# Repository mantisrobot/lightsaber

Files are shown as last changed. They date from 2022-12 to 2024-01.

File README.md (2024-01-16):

# minifig_lightsaber
Giant Scale Minifig Lightsaber Source

This source includes two libraries that have not been written byt me. The FlashStorage library and the samd21 audio library. However, I have made changes to tbe audio library to include a loop sample function.

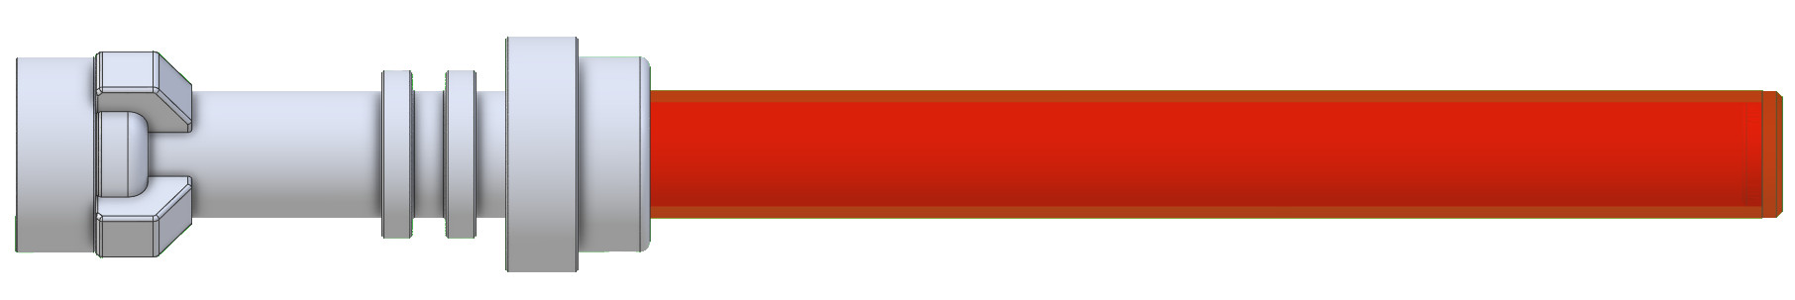
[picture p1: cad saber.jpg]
Lightsaber Minifig Lightsaber


Check out the origonal build video here:
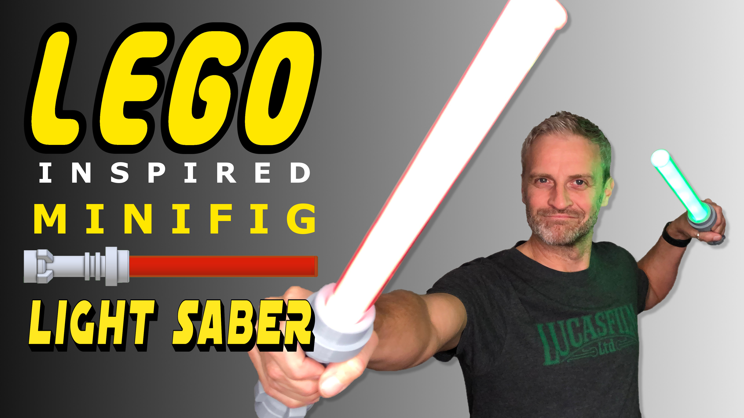
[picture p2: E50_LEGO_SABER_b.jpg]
Watch the video (https://youtu.be/OPCm9aoIxUs)


Suport my channel by purchaseing the STL files here:
https://www.threeding.com/3d-model/14297-giant-scale-minifig-light-saber

Minifig Light Saber Schematic:
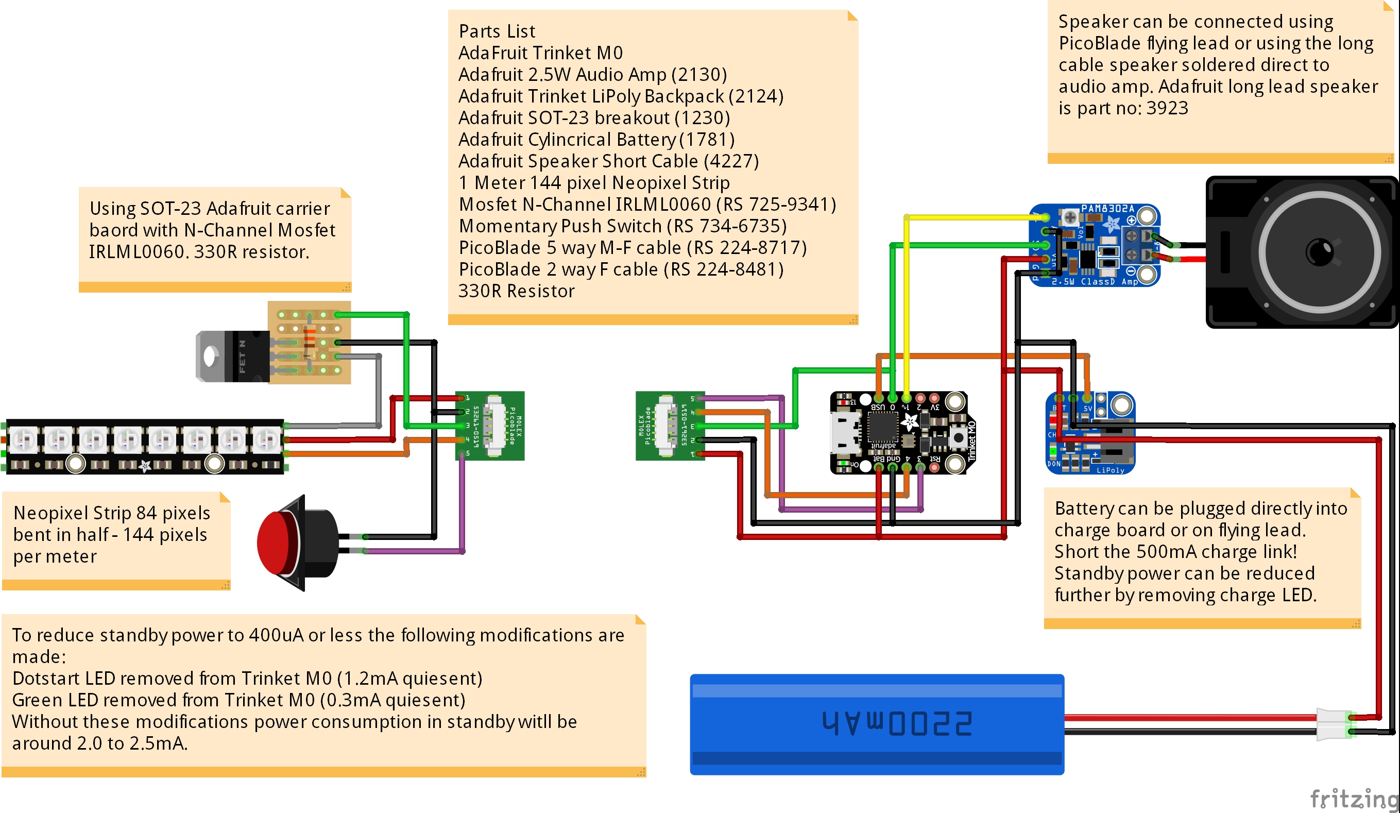
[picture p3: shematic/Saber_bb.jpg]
schematic Schematic


## Arduino Project
The arduino audio library has been modified to add a loopAudio() function. I have included my version of the library in the LIBS directory. You will need to copy the audio libray directory to your arduino libray directory.

## Parts List
Reference links provided in the [Parts List](./Denton%20Saber%20Parts.xls)

*********************************
Amazon Parts US Links:
*********************************
- Adafruit Trinket M0: https://amzn.to/3VEV7Ne
- Adafruit LiPo Backpack: https://amzn.to/3VIdf8Z
- 2.5W Class D Amplifier: https://amzn.to/3FdEK4N
- 1W Oval Speaker: https://amzn.to/3AXXmTQ
- Neopixel Strip: https://amzn.to/3XMaK7a
- SOT-23 Breakout PCB: https://amzn.to/3Ulr6AG
- Polymaker PLA Grey 1.75mm: https://amzn.to/3UnYiYk
- Polymaker PLA Grey 2.85mm: https://amzn.to/3H29UgL

*********************************
Amazon Parts UK Links:
*********************************
- Adafruit Trinket M0: https://amzn.to/3VFpXFe
- Adafruit LiPo Backpack: https://amzn.to/3VhMpEB
- 2.5W Class D Amplifier: https://amzn.to/3ESpicO
- 1W Oval Speaker: https://amzn.to/3uamDGr
- Neopixel Strip: https://amzn.to/3VzjxaM
- SOT-23 Breakout PCB: https://amzn.to/3Fexrd9
- SOT-23 Breakout PCB: https://amzn.to/3GSifDI
- 3.7V 18650 LiPo Battery: https://shop.pimoroni.com/products/lithium-ion-battery-pack?variant=23417820359
- Polymaker PLA Grey 1.75mm: https://amzn.to/3EUrOPH
- Polymaker PLA Grey 2.85mm: https://amzn.to/3H1n912
- Acrylic Tube 32x28x500mm (requires cutting down): https://amzn.to/3Uq9hAF

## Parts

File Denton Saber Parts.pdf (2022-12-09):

### Sheet1

### Page 1

# Denton Minifig Light Saber Part List

Description | Qty Link | Alternate Link List Price (US) | Notes
Adafruit Trinket M0 | 1 https://www.adafruit.com/product/3500 https://www.digikey.com/en/products/detail/adafruit-industries-llc/3500/7623049 $ | 8.95
Adafruit LiPo Backpack | 1 https://www.adafruit.com/product/2124 https://www.digikey.com/en/products/detail/adafruit-industries-llc/2124/5761211 $ | 4.95
Adafruit Speaker | 1 https://www.adafruit.com/product/4227 https://www.digikey.com/en/products/detail/adafruit-industries-llc/4227/10245140 $ | 1.95
Adafruit Amplifier | 1 https://www.adafruit.com/product/2130 https://www.digikey.com/en/products/detail/adafruit-industries-llc/2130/5761279 $ | 3.95
Adafruit SOT-23 Carrier | 1 https://www.adafruit.com/product/1230 https://www.digikey.com/en/products/detail/adafruit-industries-llc/1230/5022801 $ | 4.95
Adafruit LiPo Battery | 1 https://www.adafruit.com/product/1781 https://www.digikey.com/en/products/detail/adafruit-industries-llc/1781/5054543 $ | 9.95 | Cable may need lengthening, check polarity!
Neopixel Strip (144 pixels/meter) UK | 1 https://amzn.to/3irY999 | Either UK Link
Neopixel Strip (144 pixels/meter) US | https://amzn.to/3UjBZTU | Or US Link
Switch | 1 https://uk.rs-online.com/web/p/push-button-switches/7346735 https://www.digikey.com/en/products/detail/cit-relay-and-switch/BNP10SCQE/12503300 $ | 2.39
Picoblade Cable (5-pin) | 1 https://uk.rs-online.com/web/p/wire-to-board-cables/2248717 https://www.digikey.com/en/products/detail/molex/2181130502/14309366 $ | 4.70
Picoblade Cable (2-in) | 1 | https://www.digikey.com/en/products/detail/molex/2181110200/14309356 $ | 2.11
FET Transitor | 1 https://uk.rs-online.com/web/p/mosfets/7259341 https://www.digikey.com/en/products/detail/infineon-technologies/IRLML0060TRPBF/2202213 $ | 0.51
330R Resistor | 1 | https://www.digikey.com/en/products/detail/yageo/FMP100JR-52-330R/2058601 $ | 0.20
M2.5 Square Nut | 2 | https://www.digikey.com/en/products/detail/wakefield-vette/3654370/5432347
M2.5 x 12 Cap Head Bolt | 2 | https://www.digikey.com/en/products/detail/essentra-components/50M025045G012/11640243 $ | 0.15
Acrylic Tube | 1 https://www.ebay.co.uk/itm/200973097176?var=500191833720 | 32mm OD, 28mm ID, 300mm Length

Amazon Parts Links

### Sheet1

### Page 2

Amazon US | Amazon UK
https://amzn.to/3VEV7Ne | https://amzn.to/3VFpXFe
https://amzn.to/3VIdf8Z | https://amzn.to/3VhMpEB
https://amzn.to/3AXXmTQ | https://amzn.to/3uamDGr
https://amzn.to/3FdEK4N | https://amzn.to/3ESpicO

Cable may need lengthening, check polarity!
https://amzn.to/3XMaK7a | https://amzn.to/3VzjxaM
32mm OD, 28mm ID, 300mm Length | https://www.amazon.com/gp/product/B0B6QBDQGN/

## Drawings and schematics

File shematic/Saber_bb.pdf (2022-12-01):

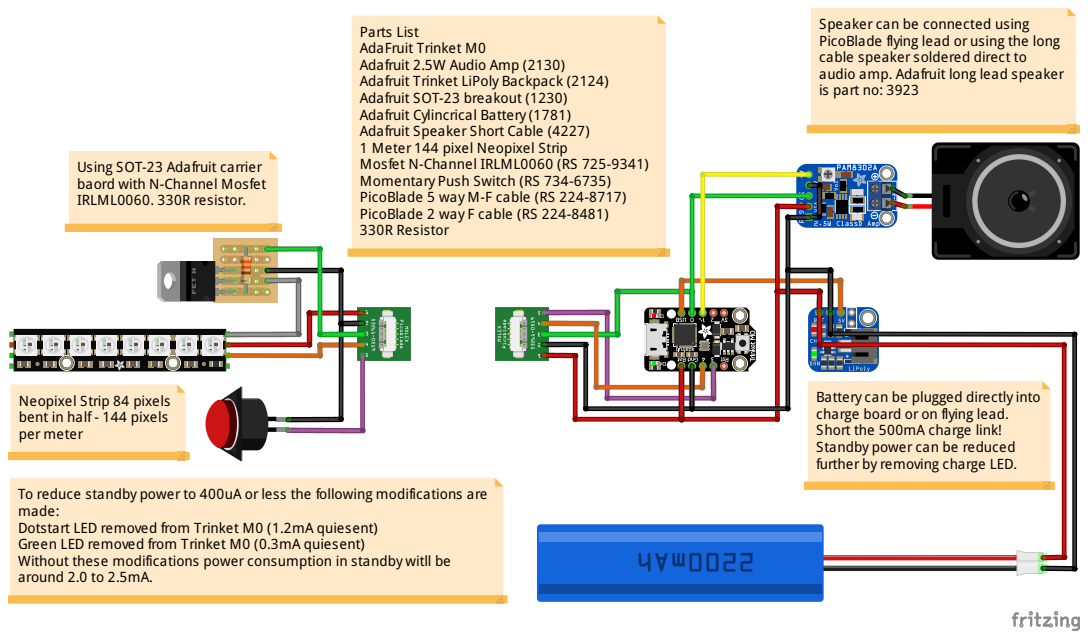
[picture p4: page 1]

Speaker can be connected using
PicoBlade flying lead or using the long
cable speaker soldered direct to
audio amp. Adafruit long lead speaker
is part no: 3923

Parts List
AdaFruit Trinket M0
Adafruit 2.5W Audio Amp (2130)
Adafruit Trinket LiPoly Backpack (2124)
Adafruit SOT-23 breakout (1230)
Adafruit Cylincrical Battery (1781)
Adafruit Speaker Short Cable (4227)
1 Meter 144 pixel Neopixel Strip
Mosfet N-Channel IRLML0060 (RS 725-9341)
Momentary Push Switch (RS 734-6735)
PicoBlade 5 way M-F cable (RS 224-8717)
PicoBlade 2 way F cable (RS 224-8481)
330R Resistor

Using SOT-23 Adafruit carrier
baord with N-Channel Mosfet
IRLML0060. 330R resistor.

Neopixel Strip 84 pixels
bent in half - 144 pixels
per meter

Battery can be plugged directly into
charge board or on flying lead.
Short the 500mA charge link!
Standby power can be reduced
further by removing charge LED.

To reduce standby powerto 400uA orless the following modifications are
made:
Dotstart LED removed from Trinket M0 (1.2mA quiesent)
Green LED removed from Trinket M0 (0.3mA quiesent)
Without these modifications power consumption in standby witll be
around 2.0 to 2.5mA.

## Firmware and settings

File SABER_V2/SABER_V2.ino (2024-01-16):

//#include <Adafruit_NeoPixel_ZeroDMA.h>
#include <Adafruit_NeoPixel.h>
#include <AudioPlayer.h>
#include <Adafruit_DotStar.h>
#include "ArduinoLowPower.h"
#include <FlashStorage.h>
#include "ON_1S.h"
#include "OFF_06S.h"
#include "HUM_3SM.h"

// NEOPIXEL DMA
// using DMA mode frees up processor use and does not distort sound, however, there is no
// mechanisim to disable the library and set the neopixel pin back to an input, which means there
// is a higher current draw in sleep mode. For this reason I have switched to the standard neopixel
// lib and uses setPin() to disable the neopixel output reducing the sleep current. Also, the 
// sound distortion produced is acceptable and actually quite good!


// this option does not playback sound, just used during development
//#define MUTE_MODE

// do not sleep when debuging / developing
// Once the device enters sleep mode, you will not be able to program the device from the arduino IDE without
// power cycling the device. This mode stops the device from going into a full sleep while developing code.
//#define DEBUG_NO_SLEEP_MODE

#define USE_INTERRUPT_PIN
// this option uses pin change wake up, much faster power on than timed sleep mode!

// defines the strip update rate
#define FRAME_RATE 50

// defines the nuber of neopixels on one side of the strip. (actual count is twice this number)
#define STRIP_LED_COUNT 42

// boot delay useful when developing
// This boot delay gives time for the device to be programmed after applying power.
// Once the device goes to sleep programming can not take effect unless a power cycle is inititated.
// See DEBUG_NO_SLEEP_MODE option above for further development mode option.
#define BOOT_TIME_WAIT  30000 // mili seconds


// ************************************************************************
// device pins
// ************************************************************************
#define PIN_ANA_OUT     A0
#define PIN_NEOPIXEL    4
#define PIN_SPARE       2
#define PIN_AMP_SHDWM   0
#define PIN_WAKE        3
#define PIN_DUMMY       9

// ************************************************************************
// AUDIO SECTION
// ************************************************************************
/*
 * WAV CONVERSION TO .h FILES
 * https://bitluni.net/wp-content/uploads/2016/12/bin2h8bit.html
 */

#define WAV_FREQUENCEY  16000
#define WAV_OVERSAMPLE  0
#define SABER_ON_TIME (saberOnSize / (WAV_FREQUENCEY/1000)) // power up time in mS
#define SABER_OFF_TIME (saberOffSize / (WAV_FREQUENCEY/1000)) // power down time in mS

// ************************************************************************
// these values set the color and intesity. I have tuned these to keep below 
// 650ma of power draw! This is due to the small wires used on the picoblade
// connector which have a mximum of 1000ma capacity.
// ************************************************************************
#define BLADE_COLOR_RED (0xA00000)
#define BLADE_COLOR_YEL (0x784200)
#define BLADE_COLOR_GRN (0x007200)
#define BLADE_COLOR_BLU (0x0000B0)
#define BLADE_COLOR_PUR (0x600060)
#define BLADE_COLOR_WHT (0x402855)

#define MAX_COLORS 6
const unsigned long saberColor[MAX_COLORS] = {BLADE_COLOR_RED,BLADE_COLOR_YEL,BLADE_COLOR_GRN,BLADE_COLOR_BLU,BLADE_COLOR_PUR,BLADE_COLOR_WHT};

// used by fast sin table
#define SIN_TABLE_SCALE 10  // fractions of a degree, e.g. 10 = 0.1 degrees per step tabel size = 360 * 10

// saber pixel array
unsigned long saberPixels[STRIP_LED_COUNT];

// saber pulse variables
#define WAVE_AMPLITUDE_RND (waveAmplitude) //(saberColorRndAmplitude[saberColIndex])
#define WAVE_FREQUENCY_MIN (20)
#define WAVE_FREQUENCY_RND (waveFrequency)
#define WAVE_PHASE_MIN     (-10)
#define WAVE_PHASE_RND     (wavePhase)


// ************************************************************************
// neopixel and dotstart strip 
// ************************************************************************
Adafruit_NeoPixel strip(STRIP_LED_COUNT * 2, PIN_NEOPIXEL, NEO_GRB);
Adafruit_DotStar dotStar = Adafruit_DotStar(1, 7, 8, DOTSTAR_BGR);

// ************************************************************************
// variables and functions
// ************************************************************************
volatile bool  wake = false;
int   saberColIndex = 0;
int   waveFrequency = 25;
int   wavePhase = 10;
float waveAmplitude = 0.5;
float degrees = 0;
float sinTable[360*SIN_TABLE_SCALE];


void wakeUp(void);
void sleepSaber(void);
void powerUpSaber(void);
void powerDownSaber(void);
void powerDownDevice(void);
void programMode(void);

// Reserve a portion of flash memory to store an "int" variable
// and call it "my_flash_store".
FlashStorage(colorFlashStore, int);


// ************************************************************************
// the setup routine runs once when you press reset:
// ************************************************************************
void setup() 
{
    // initialize the digital pin as an output.
  pinMode(PIN_LED , OUTPUT);
  pinMode(PIN_AMP_SHDWM , OUTPUT);  
  pinMode(PIN_WAKE , INPUT_PULLUP); 
  pinMode(PIN_SPARE,INPUT); 
  digitalWrite(PIN_AMP_SHDWM, 1);   // amp and nepixel ON
  analogWrite(PIN_ANA_OUT, 128);
  pinMode(PIN_NEOPIXEL , INPUT);  

// wait for serial port init
  int t = 20;  
  while(!Serial && t--) delay(100);  
  Serial.begin(115200);

// hello world debug
#ifdef HELLO_WORLD
  while(1)
    {
      digitalWrite(PIN_LED,1);
      delay(500);
      digitalWrite(PIN_LED,0);
      delay(500);
      Serial.println("Hello World!");
    }
#endif

// get the stored saber color
  saberColIndex = colorFlashStore.read();

// initialise standard neopixel library 
  strip.begin();
  strip.setPixelColor(STRIP_LED_COUNT, 0x800000);
  strip.setPixelColor(STRIP_LED_COUNT-1, 0x800000); 
  strip.show();
  
// init the dotstart and turn off the led  
  dotStar.begin();
  dotStar.setPixelColor(0, 0);
  dotStar.show();

// send the boot message to serial port
  digitalWrite(PIN_LED,1);
  Serial.print("\r\nSABER By Matt Denton\r\n\r\n");
  Serial.print("On Time = ");
  Serial.println(SABER_ON_TIME);
  Serial.print("Off Time = ");
  Serial.println(SABER_OFF_TIME);
  Serial.print("Hum Time = ");
  Serial.println(saberHumSize/(WAV_FREQUENCEY/1000));


// boot up delay (for development only)
  Serial.print("Boot Delay ");
  t = STRIP_LED_COUNT-1;
  while(digitalRead(PIN_WAKE) && t--) 
  {
    delay(BOOT_TIME_WAIT/STRIP_LED_COUNT);  
    Serial.print(">");
    digitalWrite(PIN_LED, !digitalRead(PIN_LED) );
    strip.clear();
    strip.setPixelColor((STRIP_LED_COUNT*2)-t-1, 0x000080);
    strip.setPixelColor(t, 0x000080);
    strip.show();
  }
  Serial.println();
  
// init WAV DAC output  
  Serial.println("DAC Setup..");
  DACSetup(WAV_FREQUENCEY, WAV_OVERSAMPLE);                             // Set up DAC for 16kHz playback, 4x oversampling
  Serial.println("NEO Setup..");

// clear neopixel strip
  strip.clear();
  strip.show();

// generate SIN table
  Serial.println("Generate Sin Table..");
  float d = 0;
  for( int t = 0; t < 360*SIN_TABLE_SCALE; t++ )
  {
    sinTable[t] = sin(d);
    d += (1.0/SIN_TABLE_SCALE)/57.2957795;
  }

// switch off all devices
  powerDownDevice();
}


// ************************************************************************
// the loop routine runs over and over again forever:
// ************************************************************************
void loop() 
{
  unsigned long lasttime = micros();
  int tick = 0;
  int sleepCounter = 0;

  Serial.println("Loop..");

  while(1)
  {

    // put saber to sleep
    sleepSaber();

    // power up the saber
    if( wake )
      {
        sleepCounter = 0;
        tick = FRAME_RATE;
        Serial.println("WAKE");          
        powerUpSaber();
      }

    bool relaseButton = false;

    // if operational stay in this loop
    while(wake)
      {

      // system update at set frame rate of 50Hz
      if( (micros() - lasttime) > (1000000/FRAME_RATE) )
      {
        lasttime = micros();

        // update leds
        if( wake )
        {
          // user keys to change settings ( debug mode / expreimental )
          checkKeys();
          
          // pulse the saber        
          pulseSaber();

          // update the neopixel strip
          strip.show();
        }        

        // system tick every 0.25 seconds
        if( tick++ > FRAME_RATE/4 )
        {
          tick = 0;
          // send debug message
          Serial.println("TICK");
          // blink led
          digitalWrite(PIN_LED, !digitalRead(PIN_LED) );
          // re-state pullup on swithc pin! (why is this needed?)
          pinMode(PIN_WAKE , INPUT_PULLUP);  

          // make sure button has been released
          if( digitalRead(PIN_WAKE) )
          {
            relaseButton = true;
          }

          // check for button press switch off
          if( relaseButton == true && !digitalRead(PIN_WAKE) )
          {
            digitalWrite(PIN_LED, 1 );
            // must be held for one tick cycle > 0.25 seconds
            if( ++sleepCounter > 1 )
            {
              powerDownSaber();
              sleepCounter = 0;
            }
          }
          else
            {
            sleepCounter = 0;  
            }

        }
      }
    }
  }  
}



// ************************************************************************
// put the saber to sleep 
// put the device to sleep and wait for button press
// or timeout depending on which mode is selected
// ************************************************************************
void sleepSaber()
{

// wait for button press mode
#ifdef USE_INTERRUPT_PIN  
    Serial.println("Sleep..");
    delay(10); // message delay
#ifdef DEBUG_NO_SLEEP_MODE    
    delay(150); // debounce delay
    if( !digitalRead(PIN_WAKE) )
    {
      wake = true;
    }
#else
    // wake from interrupt only seems to work if this is called before a sleep call!
    LowPower.attachInterruptWakeup(digitalPinToInterrupt(PIN_WAKE), wakeUp, FALLING);
    LowPower.sleep();  
    digitalWrite(PIN_LED, 1);
    delay(150); // debounce delay
    digitalWrite(PIN_LED, 0);
#endif    
     // debounce signal and check for definate wake up?
    if( digitalRead(PIN_WAKE) )
    {
        // no, go back to sleep.
        wake = false;
    }


// sleep wake up mode without button press 
#else  
    #ifdef DEBUG_NO_SLEEP_MODE
    delay(1000);
    #else
    LowPower.sleep(1000);  
    #endif
    // reset input pullup, (not sure why this is needed but pullup seems to be reset without!)
    pinMode(PIN_WAKE , INPUT_PULLUP);
    // blink LED
    digitalWrite(PIN_LED, 1);
    delay(1);
    digitalWrite(PIN_LED, 0);   
    // check the wake button     
    if( !digitalRead(PIN_WAKE) )
    {
        wake = true;    
    }
#endif
}

  
// ************************************************************************
// pulse the saber light  
// ************************************************************************
void pulseSaber()
{

  unsigned long time = micros();
  
  float frequency = WAVE_FREQUENCY_MIN + random(WAVE_FREQUENCY_RND);
  float amplitude = (WAVE_AMPLITUDE_RND);
  float phaseshift = random(WAVE_PHASE_RND);
  
  degrees-=phaseshift; // phase shift
  //if( degrees >= 360 ) degrees -= 360;
  //else if( degrees < 0 ) degrees += 360;


  for( int t = 0; t < STRIP_LED_COUNT; t++ )
  {
    // get the base color
    int r = (saberPixels[t] >> 16) & 0xff;
    int g = (saberPixels[t] >> 8) & 0xff;
    int b = saberPixels[t] & 0xff;
  
    // compute wave modificaion
    // using intrinsic funtion
    //float offset = 1.0 + (sin((degrees+(float(t)*frequency))/57.2957795) * amplitude); // amplitude
    // uisng lookup table 
    float offset = 1.0 + (sinT(degrees + (float(t)*frequency)) * amplitude);
    
    // modify for new rgb color
    unsigned int rn = constrain((r * offset),0,255);
    unsigned int gn = constrain((g * offset),0,255);
    unsigned int bn = constrain((b * offset),0,255);    

    // apply new color
    unsigned long rgb = (rn<<16) + (gn<<8) + bn;
    //saberPixelsModified[t] = rgb;

    strip.setPixelColor(t, rgb);
    strip.setPixelColor((STRIP_LED_COUNT*2)-t-1, rgb);
   
  }  

  //Serial.println(micros()-time);
}



// ************************************************************************
// start the saber power up sequence
// ************************************************************************
void powerUpSaber()
{
  Serial.println("Power Up Start");
  // clear pixel array
  memset(saberPixels,0,STRIP_LED_COUNT);
  // enable and clear strip
  digitalWrite(PIN_AMP_SHDWM, 1); 
  delay(1); 
  // reset neopixel pin
  strip.setPin(PIN_NEOPIXEL);
  strip.clear();
  unsigned long lasttime = millis()-(SABER_ON_TIME / STRIP_LED_COUNT);
#ifndef MUTE_MODE  
  // play wake sound
  playSample((const uint8_t*)saberOn, saberOnSize);
#endif  
  int t = 0;
  unsigned long start = millis();
  while( t < STRIP_LED_COUNT )
  {    
    if( (millis() - lasttime) > (SABER_ON_TIME / STRIP_LED_COUNT)-6 )
      {        
        lasttime = millis();
        // set color
        saberPixels[t] = saberColor[saberColIndex];
        // apply phasing
        //strip.setPixelColor(t, saberPixels[t]);
        pulseSaber();
        // update strip
        strip.show();
        t++;
      }
  }
  Serial.print("Power Up Time (mS): ");
  Serial.println(millis()-start);
  // wait sample end
  //Serial.println("WAIT SAMPLE END");   
  //while( samplePlaying() ) continue;
  Serial.println("HUM Start");   
#ifndef MUTE_MODE    
  loopSample((const uint8_t*)saberHum,saberHumSize);
#endif  

}



// ************************************************************************
// start the saber power down sequence and programming sequence
// ************************************************************************
void powerDownSaber()
{
  bool relaseButton = false;
  bool programCol = false;
  
  wake = false;
  
  digitalWrite(PIN_LED,1);
  Serial.println("SLEEP");

#ifndef MUTE_MODE    
  playSample((const uint8_t*)saberOff, saberOffSize);
#endif
  
  unsigned long lasttime = millis()-(SABER_ON_TIME / STRIP_LED_COUNT);
  int t = 0;
  while( t < STRIP_LED_COUNT )
  {    
    if( (millis() - lasttime) > (SABER_ON_TIME / STRIP_LED_COUNT)-8 )
      {        
        lasttime = millis();
        // switch off led
        saberPixels[STRIP_LED_COUNT-t-1] = 0;
        // apply phasing
        pulseSaber();
        // update strip
        strip.show();
        t++;
    
        if( relaseButton == false )
        {
          if( digitalRead(PIN_WAKE) )
          {
            Serial.println("Button release");
            relaseButton = true;
          }
        }
        else
        {
          if( !digitalRead(PIN_WAKE) && programCol == false)
            {
              programCol = true;
              Serial.println("Colour program start");
            }
        }
      }
  }    

  int pressCount = 0;
  // check for program mode
  if(programCol)
  {
    programMode();
  }
  
  // wait for release
  while(!digitalRead(PIN_WAKE))
  {
    continue;
  }
  
  pauseSample();
  Serial.println("RELEASE");
  delay(50);
  
  powerDownDevice();         
}



// ************************************************************************
// profram mode
// ************************************************************************
void programMode()
{
  // wait for switch release
    while( !digitalRead(PIN_WAKE) );

  // wait for user colour set
    int tick = 0;
    while(1)
    {
      strip.fill(saberColor[saberColIndex],0,(STRIP_LED_COUNT*2)-1);
      strip.show();
      delay(100);
      
      if( !digitalRead(PIN_WAKE) )
      {
          Serial.println("Colour program end");
          strip.clear();
          strip.show();
          colorFlashStore.write(saberColIndex);
          break;
      }

      if( tick++ > 13 )
        {
        tick = 0;
        saberColIndex++;
        if( saberColIndex > MAX_COLORS-1 ) saberColIndex = 0;
        }
    }
}

// ************************************************************************
// put device into low power state by disabling all devices
// ************************************************************************
void powerDownDevice()
{
  strip.clear();
  strip.show();
  dotStar.clear();
  dotStar.show();
  digitalWrite(PIN_AMP_SHDWM, 0);  
  digitalWrite(PIN_LED, 0);   
  // disable neopixel pin to stop leakage current through data pin
  strip.setPin(PIN_SPARE); 
}

// ************************************************************************
// faster sin lookup table
// ************************************************************************
float sinT( float din )
{
  int tp;
  int sign = 1;
  float d = din;

  if ( d < 0 )
  {
    d = -d;  
    sign = -1;
  }
  
  tp = fmod(d * SIN_TABLE_SCALE,360*SIN_TABLE_SCALE);

  if( tp >= 0 && tp < 360*SIN_TABLE_SCALE )
  {
    return sinTable[tp]*sign;
  }

  Serial.print("Table Error! ");
  Serial.print(din);
  Serial.print(" ");
  Serial.println(tp);
  return 0;
}


#ifdef USE_INTERRUPT_PIN
// ************************************************************************
// button press callback isr
// ************************************************************************
void wakeUp()
{
   wake = true;
}
#endif

// ************************************************************************
// check user keys for pulse change, useful while developing device, could
// be expanded for full user configuration via terminal port/app
// ************************************************************************
void checkKeys()
{
  while( Serial.available() )
  {
    char c = Serial.read();
    switch( c )
    {
      case 'q':
        waveAmplitude += 0.01;
        Serial.print("Wave Amplitude ");
        Serial.println(waveAmplitude);
        break;
      case 'a':
        waveAmplitude -= 0.01;
        Serial.print("Wave Amplitude ");
        Serial.println(waveAmplitude);        
        break;     
     case 'w':
        waveFrequency += 1;
        Serial.print("Wave Frequency ");
        Serial.println(waveFrequency);        
        break;   
     case 's':
        waveFrequency -= 1;
        Serial.print("Wave Frequency ");
        Serial.println(waveFrequency);        
        break;     
     case 'e':
        wavePhase += 1;
        Serial.print("Wave Phase ");
        Serial.println(wavePhase);        
        break;   
     case 'd':
        wavePhase -= 1;
        Serial.print("Wave Phase ");
        Serial.println(wavePhase);        
        break;               
    }
  }
}

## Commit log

2022-12-01 Parts Update + Scheamtic
    Parts list added with links
    Schematic & Fritzing file added
    [Denton Saber Parts.xls, Saber.fzz]
2022-12-01 Parts List Update + Image Update
    [Denton Saber Parts.xls]
2022-12-01 Parts Update
    [Denton Saber Parts.xls]
2022-12-08 updating parts list with digikey links
    [Denton Saber Parts.xls]
2024-01-16 Added notes about lowpower mode programming / boot up
    1) Added notes about lowpower mode programming / boot up
    2) Added the Arduino_low_power library to the LIBS directory, however this should be downloaded using the library manager.
    3) Updated README.md
